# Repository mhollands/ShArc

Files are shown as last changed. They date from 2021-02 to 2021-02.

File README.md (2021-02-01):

# ShArc

I recreated the work from [this paper!](https://dl.acm.org/doi/10.1145/3313831.3376269)

I use an AD7446 to sense mutual capacitance between TX and RX electrodes of 4 pixels on a pair of flexes. This capacitance varies approximately linearly with the curvature of the two flexes. An STM32 microcontroller bridges the gap between the host computer and AD7446 via USB. The design has four parts:

- Sense board which holds the electronics and connects to the host computer via USB
- RX Flex which has 4 receive electrodes
- TX Flex which has 4 transmit electrodes
- Separator which is a dumb piece of polymide material to fit between the RX and TX flexes

Schematics and gerbers can be found for each part and the design was build using OSHPark standard PCBs and Flexes.

Watch the video (https://youtu.be/9scRBK16ceY)

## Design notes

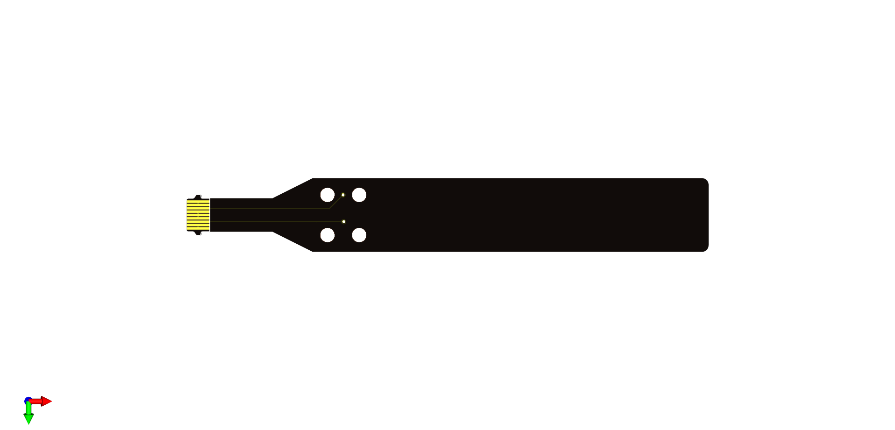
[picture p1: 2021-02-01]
SenseBoard/center_4pix/TX_Flex/TX_Flex/TX_Flex_bottom.png

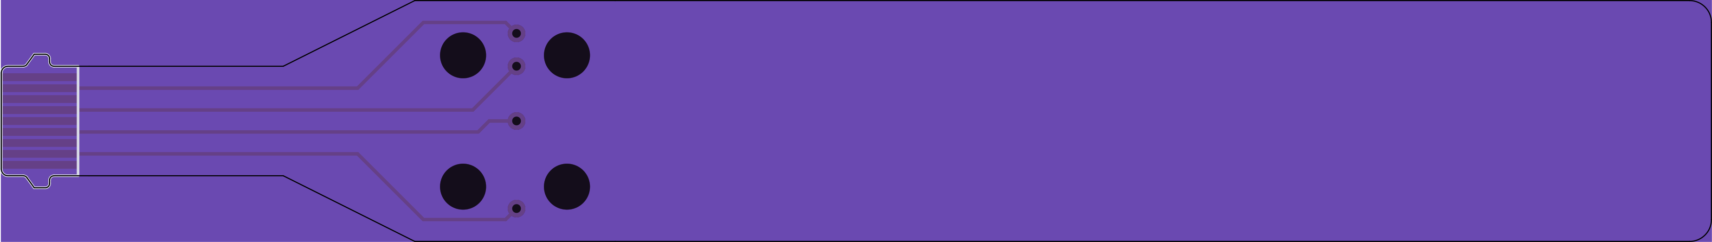
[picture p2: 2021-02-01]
SenseBoard/center_4pix/RX_Flex/plot/RX_Flex-Front.png

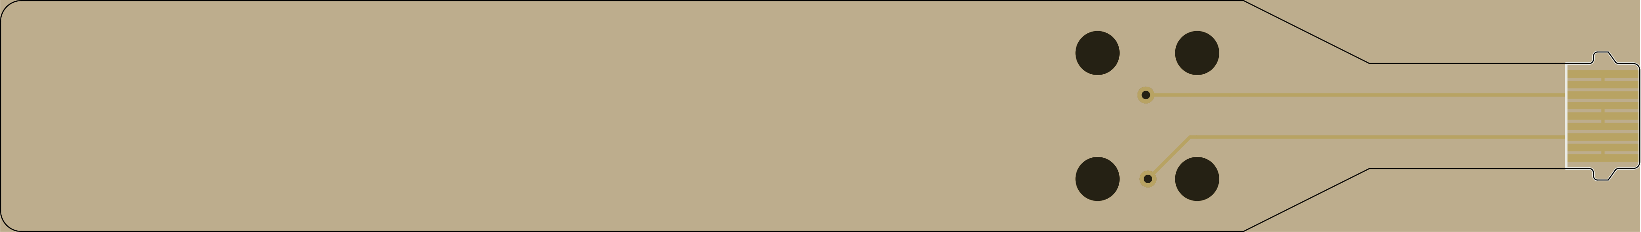
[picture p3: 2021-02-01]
SenseBoard/center_4pix/TX_Flex/TX_Flex/plot/TX_Flex-Back.png

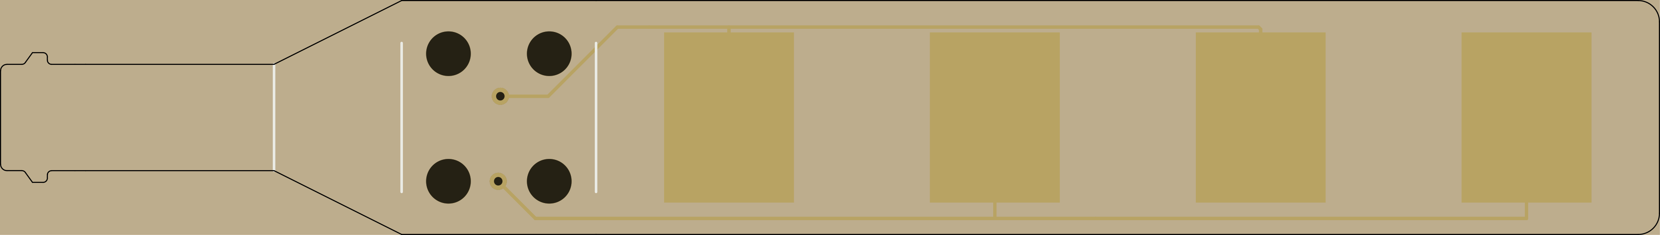
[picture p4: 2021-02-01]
SenseBoard/center_4pix/TX_Flex/TX_Flex/plot/TX_Flex-Front.png

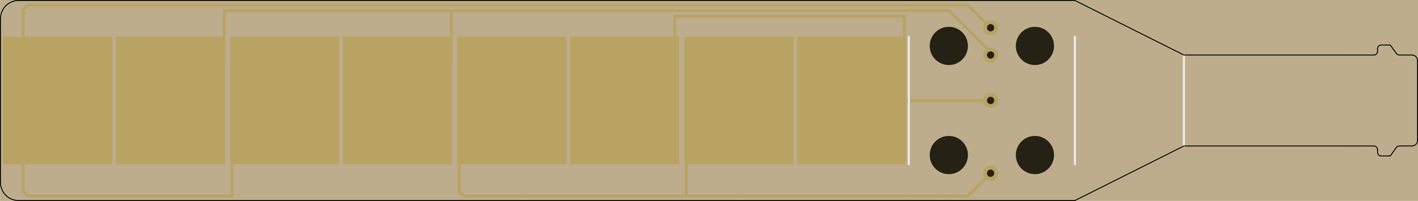
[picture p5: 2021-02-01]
SenseBoard/center_4pix/RX_Flex/plot/RX_Flex-Back.png

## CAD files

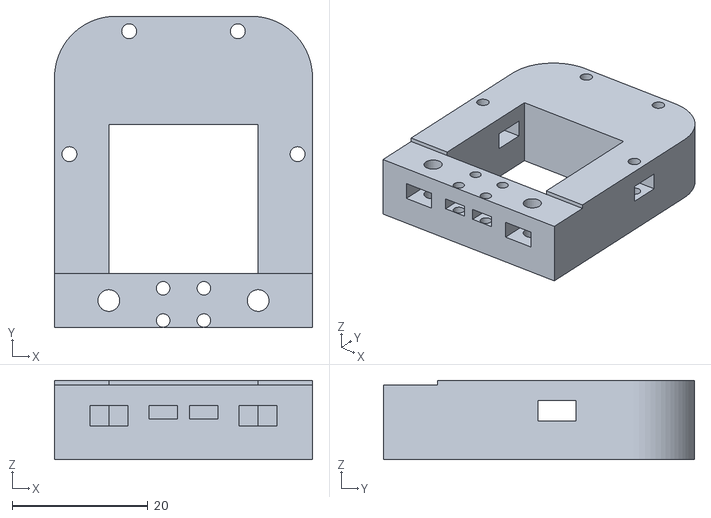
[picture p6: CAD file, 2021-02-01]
CAD/Body_v17.stl
38.0 x 45.9 x 11.7

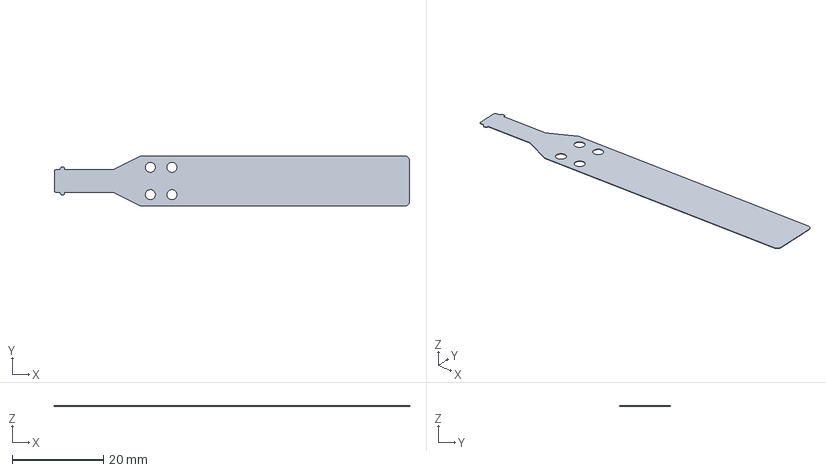
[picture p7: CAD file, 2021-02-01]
SenseBoard/center_4pix/RX_Flex/RX_Flex.step
78.0 x 11.0 x 0.102 mm

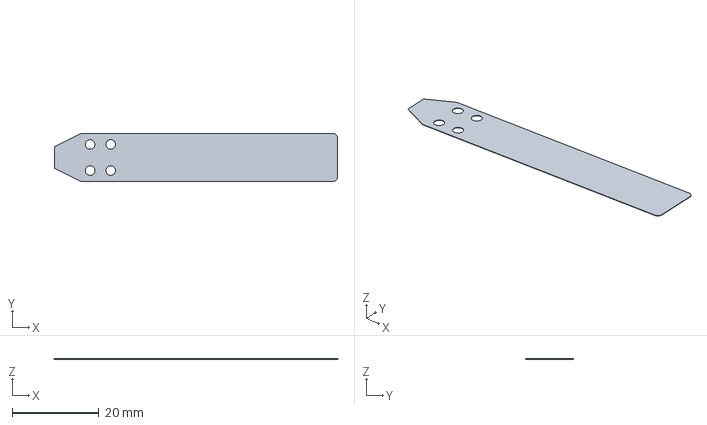
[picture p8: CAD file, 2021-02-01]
SenseBoard/center_4pix/Separator/Separator/Separator.step
65.1 x 11.0 x 0.102 mm

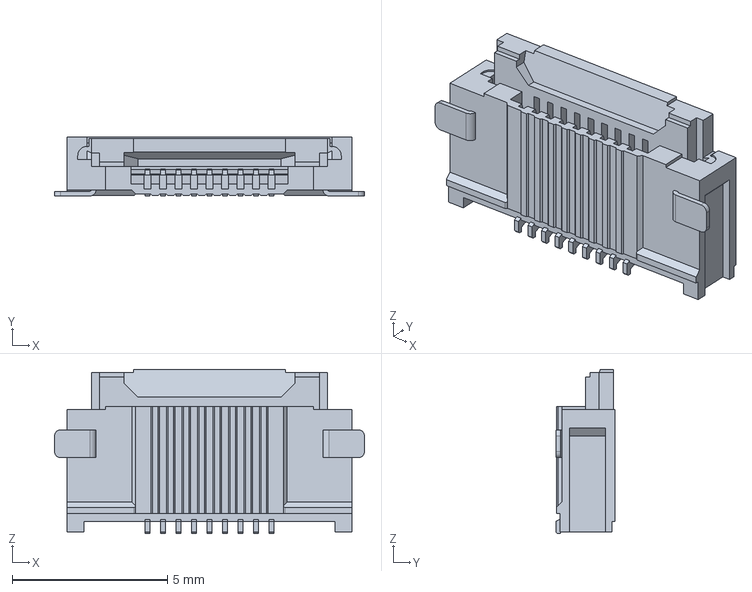
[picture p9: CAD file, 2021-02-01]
SenseBoard/center_4pix/Sense_board/5051100992.stp
10.0 x 1.90 x 5.30 mm

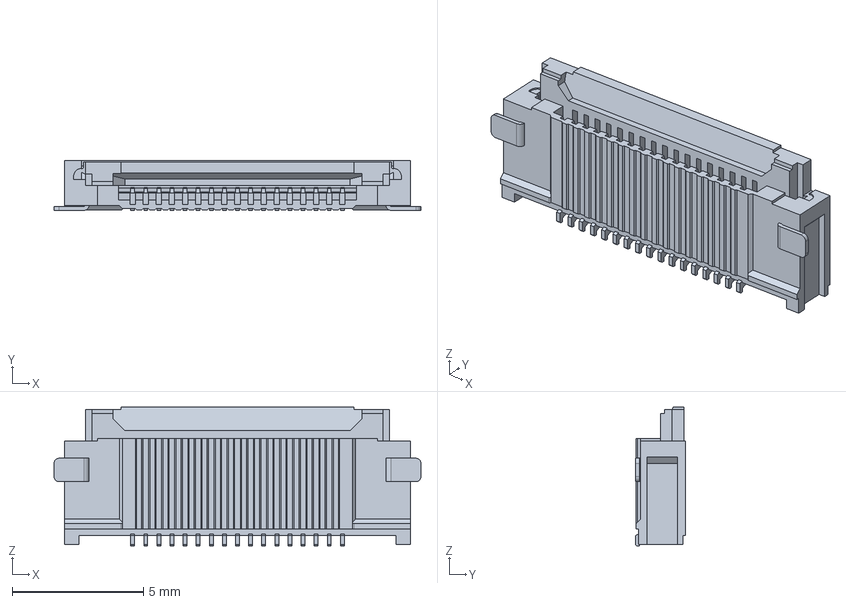
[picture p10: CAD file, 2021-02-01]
SenseBoard/center_4pix/Sense_board/5051101792.stp
14.0 x 1.90 x 5.30 mm

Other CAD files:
SenseBoard/center_4pix/TX_Flex/TX_Flex/TX_Flex.step

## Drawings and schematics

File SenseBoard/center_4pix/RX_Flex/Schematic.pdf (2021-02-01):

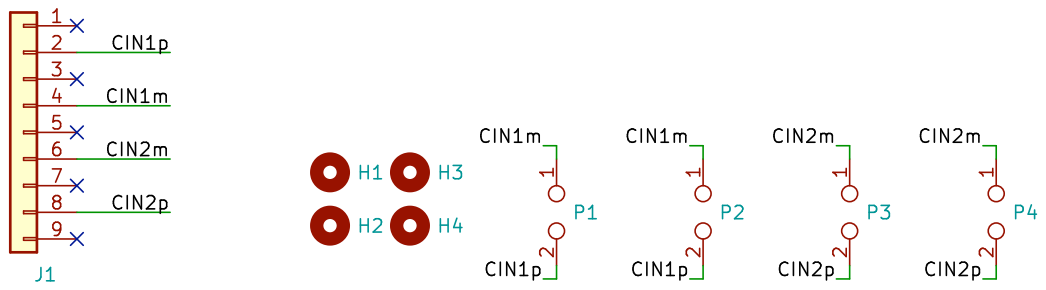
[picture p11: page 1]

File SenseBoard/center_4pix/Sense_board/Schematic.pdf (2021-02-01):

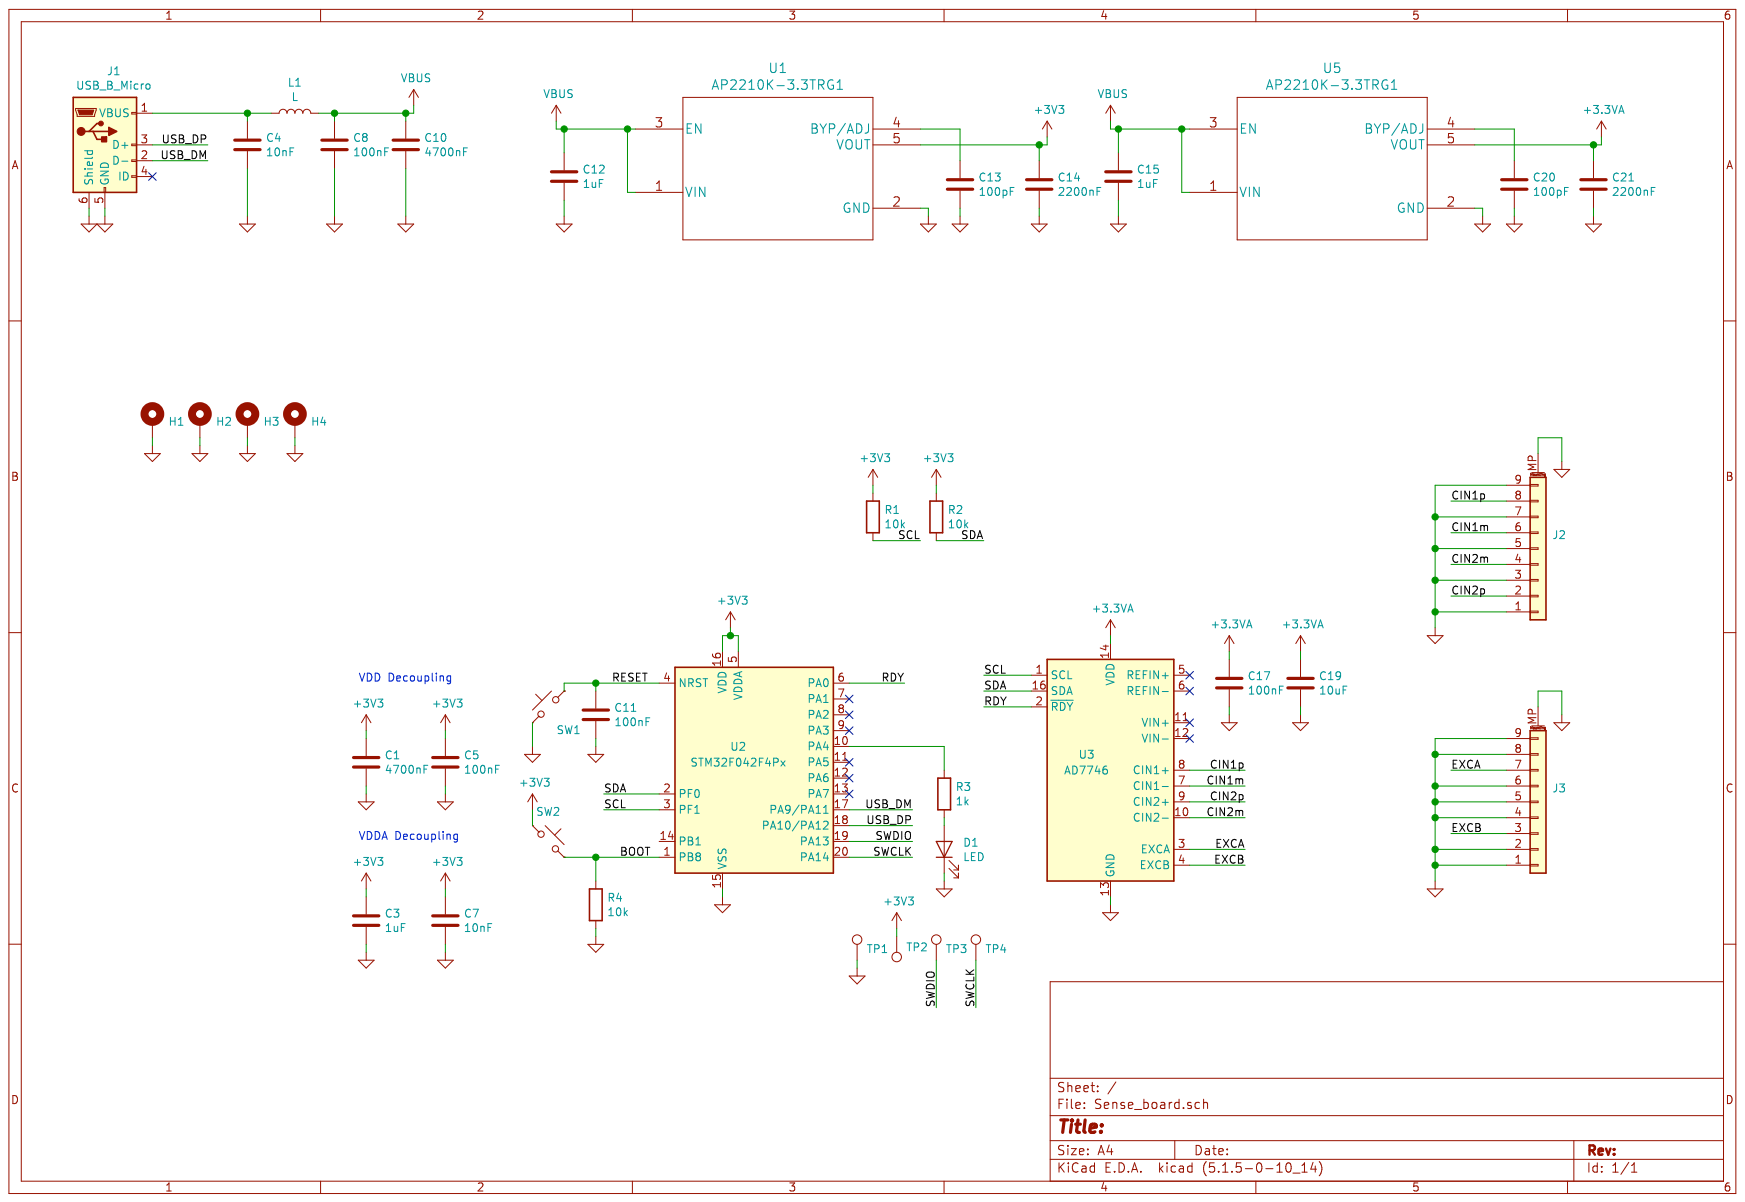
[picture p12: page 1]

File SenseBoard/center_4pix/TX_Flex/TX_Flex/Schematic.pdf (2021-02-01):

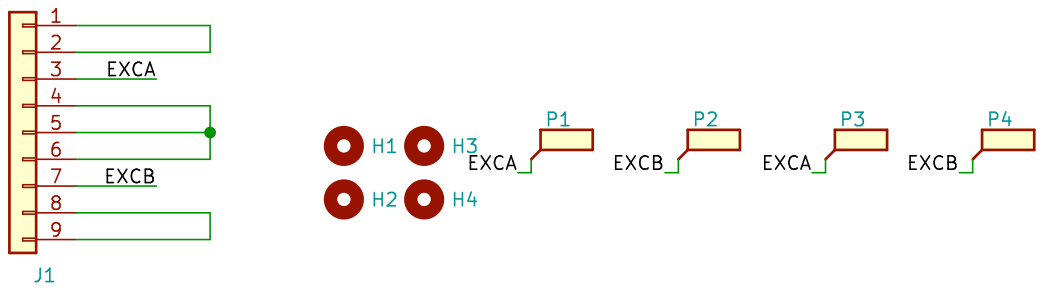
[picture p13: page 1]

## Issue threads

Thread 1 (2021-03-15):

Trouble getting meaningful data out of the AD7746.

0y8w1x, 2021-03-15:
Hey, I ordered your PCB and the FPC aswell, since I didn't find a supplier for the STM32 you used I used 3 cables to connect another STM board to SCL, SDA, and the RDY pin. I think that's all I need to interface with the AD7746 (correct me if I'm wrong).
Anyways, I assembled everything but couldn't make sense of the `pixel_data` array. It's always reading 0's. When I touch it it occasionally reads something else. But it's not working so good.

Then I gave it another shot with my own design. I broke the AD7746 out, and designed some FPC boards. I will attach the FPC only, because the breakout board is exactly that. only a breakout of the pins. I double dna triple checked that every contact on the FPC goes to the right pin on the AD7746, but it's the same, I only get some values that are not changing. What's odd though, is that the RDY pin works fine, indicating that the AD7746 does push out data.

Any ideas how to troubleshoot that problem ?

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

0y8w1x, 2021-03-16:
Alright, I think I solved it. The problem was that the chip was dead. I tried it with two chips, both didn't work so I thought it's too unlikely that both are dead. But trying a third one and it works now.

Closed 2021-03-16.

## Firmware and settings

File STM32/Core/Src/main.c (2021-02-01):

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

/* Includes ------------------------------------------------------------------*/
#include "main.h"
#include "usb_device.h"

/* USER CODE BEGIN PTD */
// All scans in differential mode,  {CIN 1, CIN1, CIN2, CIN2}
uint8_t CAP_SETUP_SETTINGS[4] = { 0xA0, 0xA0, 0xE0, 0xE0};
// All scans full voltage,  {EXC A, EXC B, EXCA, EXCB}
uint8_t EXC_SETUP_SETTINGS[4] = { 0x08, 0x20, 0x08, 0x20};
/* USER CODE END PTD */

/* USER CODE BEGIN PD */
#define AD_ADDR 0x90
#define CAP_SETUP 0x07
#define EXC_SETUP 0x09
#define CAP_DATA 0x01
/* USER CODE END PD */

I2C_HandleTypeDef hi2c1;

/* USER CODE BEGIN PV */
uint8_t AD_RESET = 0xBF;
/* USER CODE END PV */

void SystemClock_Config(void);
static void MX_GPIO_Init(void);
static void MX_I2C1_Init(void);
/* USER CODE BEGIN PFP */
HAL_StatusTypeDef AD_SEND_RESET(void);
/* USER CODE END PFP */

/**
  * @brief  The application entry point.
  * @retval int
  */
int main(void)
{
  

  /* MCU Configuration--------------------------------------------------------*/

  /* Reset of all peripherals, Initializes the Flash interface and the Systick. */
  HAL_Init();

  /* Configure the system clock */
  SystemClock_Config();

  /* Initialize all configured peripherals */
  MX_GPIO_Init();
  MX_I2C1_Init();
  MX_USB_DEVICE_Init();
  /* USER CODE BEGIN 2 */
//  HAL_I2C_Master_Transmit(&hi2c1, AD_ADDR, &AD_RESET, 1, HAL_MAX_DELAY);
  HAL_I2C_Mem_Write(&hi2c1, AD_ADDR, 0xBF, 1, 0x00, 1, HAL_MAX_DELAY);
  // Enable Cap measurement and differential mode
  /* USER CODE END 2 */
 
 

  /* Infinite loop */
  /* USER CODE BEGIN WHILE */
  uint8_t pixel_data[4] = {0x00, 0x00, 0x00, 0x00};
  uint8_t mode = 0x05;
  uint8_t capdac_calA[4] = {0x00, 0x00, 0x00, 0x00};
  uint8_t capdac_calB[4] = {0x00, 0x00, 0x00, 0x00};
  while (1)
  {
	  for(pixel_data[0] = 0; pixel_data[0] < 4; pixel_data[0]++)
	  {
		  if(mode == 0x02)
		  {
			  // Setup up capacitance measurement settings
			  HAL_I2C_Mem_Write(&hi2c1, AD_ADDR, 0x0D, 1, (uint8_t *)&capdac_calA[pixel_data[0]], 1, HAL_MAX_DELAY);
			  HAL_I2C_Mem_Write(&hi2c1, AD_ADDR, 0x0E, 1, (uint8_t *)&capdac_calB[pixel_data[0]], 1, HAL_MAX_DELAY);
		  }
		  // Setup up capacitance measurement settings
		  HAL_I2C_Mem_Write(&hi2c1, AD_ADDR, CAP_SETUP, 1, &CAP_SETUP_SETTINGS[pixel_data[0]], 1, HAL_MAX_DELAY);
		  // Set up excitation settings
		  HAL_I2C_Mem_Write(&hi2c1, AD_ADDR, EXC_SETUP, 1, &EXC_SETUP_SETTINGS[pixel_data[0]], 1, HAL_MAX_DELAY);
		  // Begin scan
		  HAL_I2C_Mem_Write(&hi2c1, AD_ADDR, 0x0a, 1, &mode, 1, HAL_MAX_DELAY);
		  // Wait for RDY to be low
		  while((RDY_GPIO_Port->IDR & RDY_Pin) != 0){}
		  // Read back the data
		  HAL_I2C_Mem_Read(&hi2c1, AD_ADDR, CAP_DATA, 1, &pixel_data[1], 3, HAL_MAX_DELAY);
		  if(mode == 0x05)
		  {
			  HAL_I2C_Mem_Read(&hi2c1, AD_ADDR, 0x0D, 1, (uint8_t *)&capdac_calA[pixel_data[0]], 1, HAL_MAX_DELAY);
			  HAL_I2C_Mem_Read(&hi2c1, AD_ADDR, 0x0E, 1, (uint8_t *)&capdac_calB[pixel_data[0]], 1, HAL_MAX_DELAY);
		  }
		  // Send via USB
		  CDC_Transmit_FS(&pixel_data, 4);
		  HAL_GPIO_TogglePin(LED_GPIO_Port, LED_Pin);
		  // Wait for RDY to be high
		  while((RDY_GPIO_Port->IDR & RDY_Pin) == 0){}
	  }
	  mode = 0x02;
    /* USER CODE END WHILE */

    /* USER CODE BEGIN 3 */
  }
  /* USER CODE END 3 */
}

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


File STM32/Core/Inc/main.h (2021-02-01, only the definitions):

#define RDY_Pin GPIO_PIN_0
#define RDY_GPIO_Port GPIOA
#define LED_Pin GPIO_PIN_4
#define LED_GPIO_Port GPIOA

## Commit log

2021-02-01 add STM32 FW files
2021-02-01 add kicad files
    [5051100992.stp, 5051101792.stp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]
2021-02-01 add cad for 3d printed base
    [Body_v17.stl]

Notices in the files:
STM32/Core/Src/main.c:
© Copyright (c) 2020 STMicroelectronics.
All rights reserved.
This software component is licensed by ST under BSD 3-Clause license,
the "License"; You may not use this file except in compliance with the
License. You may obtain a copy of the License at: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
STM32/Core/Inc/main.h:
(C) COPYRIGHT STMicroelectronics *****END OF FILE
